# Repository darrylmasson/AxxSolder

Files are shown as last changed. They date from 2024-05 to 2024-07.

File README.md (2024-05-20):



Note - this is a fork of AxxSolder that replaces the MCU with the RP2040 because I felt like it. Major portions of this README will be rewritten at some point.

# AxxSolder Overview
AxxSolder is a STM32 based soldering iron controller for JBC C115, C210 and C245 cartridges. 
Two different versions are designed around the same PCB and software - one soldering station based on the [JBC ADS stand](https://www.jbctools.com/ad-sf-stand-for-t210-t245-handles-product-2018.html) and one portable version. The hardware takes a USB-C Power Delivery source. If a 65W, 20V USB-PD supply is used then NT115 and T210 handles can be powered at full power and T245 at limited power. The software is written for the RP2040 and implements a PID for temperature control, TFT display driver, sleep function when the handle is at rest and functions for read/write user settings to flash. Enclosures for both station and portable versions are 3D printed and design files are available under [/CAD](https://github.com/AxxAxx/AxxSolder/tree/main/CAD). A video showing the AxxSolder station can be found under [DEMO](#demo). A *bill of materials* (BOM) with individual component prices can be found under [/bom](https://github.com/AxxAxx/AxxSolder/tree/main/AxxSolder_hardware/bom).  
coverphoto

# Questions and support
Please use [Discord](https://discord.gg/dRD2ZfmyHY) for build related and general questions.

# Table of Contents
- [AxxSolder Overview](#axxsolder-overview)
- [Questions and support](#questions-and-support)
- [Features](#features)
- [Cartridge differences](#cartridge-differences)
- [Schematic](#schematic)
- [PCB](#pcb)
- [Software Version History and Hardware Compatibility](#software-version-history-and-hardware-compatibility)
- [DEMO](#demo)
- [AxxSolder Station](#axxsolder-station)
- [AxxSolder Portable](#axxsolder-portable)
- [Recommended power supply](#recommended-power-supply)
- [Handle identification and connections](#handle-identification-and-connections)
- [Firmware update](#firmware-update)
- [First start up after build](#first-start-up-after-build)
- [Settings](#settings)
- [PID control](#pid-control)
- [Temperature calibration](#temperature-calibration)
- [Temperature measurement](#temperature-measurement)

# Features
- The tip temperature is set by a rotary encoder. Pressing the encoder puts AxxSolder into Sleep mode and heating is turned off, press again to wake up.  
- AxxSolder is capable of driving C115, C210 and C245 style cartridges from JBC. With the "H_sense1" and "H_sense2" inputs AxxSolder can determine if the connected handle is either a NT115, T210 or T245 and adjust max output power accordingly. The max power output is limited in software to 120W for T245, 60W for T210 and 20W for NT115 handles.
- When the handle is put into the stand (connected to Stand_sense) AxxSolder goes into "Standby mode". On the portable version an aluminium plate is mounted and allows the AxxSolder to go into Standby mode when the cartridge or handle rests against it. After 10 min in Standby mode AxxSolder goes into "Sleep mode" and turns heating completely off. This is similar to what JBC calls [Sleep and Hibernation](https://www.jbctools.com/intelligent-heat-management.html).  
- If AxxSolder is left in normal running mode for longer than 30 min, the station automatically goes into sleep mode after 30 min as a safety feature.  
- Should the temperature ever go higher than 480 deg C overheating is detected and the station goes into sleep mode in order to protect the tip.
- User settings are stored in non volatile flash and can be configured via a settings menu described in [SETTINGS](#settings).
- The two buttons are used to store temperature presets, e.g. 330 deg C and 430 deg C. Both preset temperatures are configurable in the settings menu.
- The TFT display used in this project is a 2 inch 320x240 Color TFT display [2.0" 320x240 Color IPS TFT Display](https://www.adafruit.com/product/4311) and shows information about:
  - Set temperature
  - Actual temperature
  - Current power as a bar graph
  - In case of sleep mode, the power bar shows "ZzZzZz"
  - In case of Standby mode, the power bar shows "STANDBY"
  - Input voltage
  - MCU temperature
  - Current detected handle type

# Cartridge differences
Cartridges from JBC do all contain a thermocouple element to read the tip temperature and a resistive heater element. The configuration of thermocouple and heater element differ slightly between cartridge models. In order to determine the internal configuration of the cartridges two cross sections were done. These show clearly how the C210 and C245 cartridges are constructed internally. The images can be seen here: [https://www.eevblog.com/forum/projects/axxsolder-jbc-soldering-controller](https://www.eevblog.com/forum/projects/axxsolder-jbc-soldering-controller/msg5124267/#msg5124267).
As the thermocouple output also differs (see my measurements [Temperature calibration](#temperature-calibration)) the correct handle/cartridge type has to be set. This is done automatically be the inputs "Handle_sense_1" and "Handle_sense_2" This can be done thanks to the design of the handle connector. For the JCB T210 handle pin 5 and 6 are connected internally in the connector and for NT115 pin 3 and 5 should be connected. This allows AxxSolder to sense which handle is connected and assign correct thermocouple correction, PID parameters and max output power.

# Schematic
The schematic for AxxSolder is shown below. Both station and portable versions use the same PCB and software. The MCU is a [STM32G431CBT6](https://www.st.com/en/microcontrollers-microprocessors/stm32g431cb.html). 
AxxSolder_station

# PCB
The PCBs are designed in KiCad and manufactured by [PCBWay](https://www.pcbway.com/). PCBWay has sponsored this project with PCBs and stencils. As usual the quality of the PCBs is great. As some components have a rather fine pitch (0,5 mm as of the LQFP-48 package of the STM32) and some packages are "no lead" with a bottom thermal pad e.g. the WSON-8 package of the OPA2387 it is suggested to use a stencil to apply solder paste and then reflow the board using either a reflow oven or hot-plate. The boards on the image below were reflowed on a hot-plate (a homemade AxxPlate). A microscope is also recommended and helpful during assembly.
Printed Circuit Boards with assembled components are shown in the image below.
PCB_image
A 3D view (from and back) of the AxxSolder PCB is generated with KiCad and shown below. 
PCB_3D

# Software Version History and Hardware Compatibility
| Version | Date  | Hardware Compatibility |
|---|---|---|
|[v3.0.2](https://github.com/AxxAxx/AxxSolder/releases/tag/v3.0.1)|Apr 25, 2024|V3.*|
|[v3.0.1](https://github.com/AxxAxx/AxxSolder/releases/tag/v3.0.1)|Mar 26, 2024|V3.*|
|[v3.0.0](https://github.com/AxxAxx/AxxSolder/releases/tag/v3.0.0)|Mar 02, 2024|V3.*|
|[v2.2.4](https://github.com/AxxAxx/AxxSolder/releases/tag/v2.2.2)|Dec 11, 2023|V2.*|
|[v2.2.4](https://github.com/AxxAxx/AxxSolder/releases/tag/v2.2.2)|Nov 28, 2023|V2.*|
|[v2.2.3](https://github.com/AxxAxx/AxxSolder/releases/tag/v2.2.2)|Nov 25, 2023|V2.*|
|[v2.2.2](https://github.com/AxxAxx/AxxSolder/releases/tag/v2.2.2)|Oct 24, 2023|V2.*|
|[v2.2.0](https://github.com/AxxAxx/AxxSolder/releases/tag/v2.2.0)|Oct 20, 2023|V2.*|
|[v2.1.3-revC](https://github.com/AxxAxx/AxxSolder/releases/tag/v2.1.3-revC)|Oct 16, 2023|V2.*|
|[v2.1.1](https://github.com/AxxAxx/AxxSolder/releases/tag/v2.1.1)|Oct 7, 2023|V2.*|
|[v2.1.0](https://github.com/AxxAxx/AxxSolder/releases/tag/v2.1.0)|Oct 7, 2023|V2.*|

# DEMO
(This shows AxxSolder 2 and not the latest AxxSolder 3)  
Click on the gif to get to YouTube and see the demo in full resolution.  
AxxSolder DEMO (https://www.youtube.com/watch?v=-3MtJyTwZFQ)

# AxxSolder Station
The preferred setup is to pair AxxSolder with the [JBC ADS stand](https://www.jbctools.com/ad-sf-stand-for-t210-t245-handles-product-2018.html). This makes a very nice, compact and powerful soldering station. The JBC ADS stand is paired with a custom 3D printed enclosure for AxxSolder and the PCB is mounted with two mounting brackets. All 3D printed parts are available under [/CAD](https://github.com/AxxAxx/AxxSolder/tree/main/CAD). 
AxxSolder_station  
The JBC ADS stand comes with a silicone cable fitted with two Binder 99-0621-00-07 connectors. In order to use this cable a Binder 99-0624-00-07 is mounted into the AxxSolder enclosure and wired as the image below:  
AxxSolder_station  
By default, the stand separates the two signals coming from the "tool rest position" and the "tip change position" and does NOT have two separate connections for tip sensing 1 and 2 (as is needed). Therefore, a modification is done to the PCB inside the JBC ADS stand in order to combine the "tool rest position" and the "tip change position" sense into one connection and separate the two tip sense connections. This is shown in the image above. The stand is held together with two PH0 screws from the side. 

# AxxSolder Portable
It is often nice to have a compact and portable soldering iron controller for when you are away from your comfortable desk. A neat powerful package with the same capabilities as your main soldering station. This is why AxxSolder Portable was designed. The only difference between AxxSolder station and Portable is the enclosure. As AxxSolder accepts an input of 9-24 V it is compatible with a range of battery options. The author usually use a battery pack consisting of 12 Samsung INR18650 35E in a 3S4P configuration which works very well. The portable version has an aluminium tab on the enclosure connected to the same input on the PCB as the "handle rest" on the station version. This allows the user to rest the iron onto the aluminium tab and automatically enter sleep mode.   
AxxSolder_portable
The connections from the handle to the PCB through the Hirose RPC1-12RB-6P(71) connector is shown below. The blue wire in the portable version is connected to the aluminium plate which tells the AxxSolder to go into sleep mode when in contact with the soldering iron. The yellow wire is connected to pin 6 and is used to determine which handle is connected.
AxxSolder_portable
# Recommended power supply
A well-suited power supply with isolated output (SELV) is the Meanwell LRS-150-24. It is rated for 156 W at 24 V. A cover protecting the terminals for this power supply can be found under [/CAD](https://github.com/AxxAxx/AxxSolder/tree/main/CAD).  
LRS-150-24

# Handle identification and connections
In order for AxxSolder to know which type of handle (NT115, T210, T245) is connected specific pins must be connected within the handle connector. By default, the original JBC handle T245 has NO pins connected while in the original T210 pins 5 and 6 are connected. The original NT115 handle has a different connector from JBC and must be modified. If the user changes the connector or uses a non-genuine handle it is important to make sure that pin 5 and 3 is connected within the connector. All the necessary connections are shown in the image below. While powering on AxxSolder fir the first time after doing these connections within the handle connector or connections to AxxSolder it is wise to attach a handle without its cartridge and ensure that AxxSolder shows the correct handle type on the display. Failing to detect the handle type will cause damage to the tip as the thermal calibration and max power allowed will be wrong.  
Handle_connections

# Firmware update
Programming or updating the firmware the STM32 MCU can be done in two ways, by using a SWD programmer or directly via USB. 
## SWD programmer
These come in a variety of models and are available from several different places online. In the below example a [STLINK-V3MINIE](https://www.st.com/en/development-tools/stlink-v3minie.html) SWD programmer is used. The MCU is programmed by the following steps:
1. Disconnect any soldering iron handles from AxxSolder during the firmware update process.
2. Download the latest AxxSolder.bin file from [Releases](https://github.com/AxxAxx/AxxSolder/releases)
3. Connect your SWD programmer to the target MCU with GND, 3.3V, (N)RST, SWCLK, SWDIO
4. If your SWD programmer *can not* supply 3.3V it is necessary to power the AxxSolder from an external supply.
5. Start your programming software. [STM32CubeProgrammer](https://www.st.com/en/development-tools/stm32cubeprog.html) is used in this example.
6. Connect to the target by selecting *ST-LINK* and click on *Connect*
7. Load the latest AxxSolder.bin downloaded in *Step 2* by clicking *Open file* and select the downloaded binary file.
8. Write the firmware to the MCU by clicking *Download*.
9. If you get the message *File download complete* everything succeeded and the SWD programmer can be disconnected and AxxSolder power cycled once and AxxSolder should boot.


AxxSolder_SWD_programming
## USB (DFU mode)
1. Disconnect any soldering iron handles from AxxSolder during the firmware update process.
2. Download the latest AxxSolder.bin file from [Releases](https://github.com/AxxAxx/AxxSolder/releases)
3. Connect AxxSolder via USB to a computer that runs [STM32CubeProgrammer](https://www.st.com/en/development-tools/stm32cubeprog.html).
4. Hold down the most right button while powering on AxxSolder to enter DFU mode.
5. Connect to the target by selecting *USB* and click on *Connect*
6. Load the latest AxxSolder.bin downloaded in *Step 2* by clicking *Open file* and select the downloaded binary file.
7. Write the firmware to the MCU by clicking *Download*.
8. If you get the message *File download complete* everything succeeded and the USB cable can be disconnected.
9. Power cycle once and AxxSolder should boot.

# First start up after build
The first start up after you have built your AxxSolder can be intense. Double check all solder connections under a loupe/microscope. Especially the OPA2387, LTC4440 and the STM32G431 are small packages with tight pad spacing and can have solder bridges. Do also double check the connections to the soldering iron/stand which are shown in this document under [AxxSolder Station](#axxsolder-station) and [AxxSolder Portable](#axxsolder-portable).  
The first thing to do after you have double-checked everything is to follow the steps under [Firmware update](#firmware-update). It is wise to do the first programming of AxxSolder without any handle piece and with only 3.3 V, not VDD. After the programming is done you can now power up AxxSolder again via either with 3.3 V, this time you can attach your handle. This allows you to test that your handle type is detected correctly (the detected handle type NT115/T210/T245 is shown in the display). The Standby feature can also be tested by touching the stand (STAND Input).  
If the handle is detected correctly, the Standby function works and the display works you proceed to test the 7.35V DC/DC. This is done by once again disconnect the handle, but this time apply current limited 9-24 V VDD. 100 mA at 24 V is enough to check that the display starts and that you can measure the 3 bus voltages; 3.3V, 7.35V and VDD. If the bus voltages look good and the display shows the main screen you are ready to apply full VDD power and attach the soldering handle.  
If you are not 110% sure about your soldering/connections it is wise to be on the safe side and keep your soldering tip in a water bath in over to prevent it from over-heating in an uncontrolled manner. During the development this method was used and saved a few of those expensive JBC cartridges..

# Settings
To access the user settings the user holds down the encoder button at start-up. A SETTINGS text is then presented and the button can be released. While in the settings there are several parameters available.
| Setting | Desciption  | Unit | Default |
|---|---|---|---|
|Startup Temp|Default temperature selected after boot|deg C|330|
|Temp Offset|Temperature offset applied to measured temperature|deg C|0|
|Standby Temp|Temperature to go to after handle is set in stand|deg C|150|
|Standby Time|Time for which standby temperature is held before cooling down|minutes|10|
|Sleep Time|Time that the iron can be ON before cooling down (safety feature)|minutes|30|
|Buzzer Enable|Enable or Disable the buzzer|ON/OFF|ON|
|Preset Temp 1|Preset temperature for button 1|deg C|330|
|Preset Temp 2|Preset temperature for button 2|deg C|430|
|GPIO4 ON at run|Enable 3.3V output on GPIO4 when the iron is in run mode|ON/OFF|OFF|
|Screen rotation|Rotate the screen|"0"=-180 deg, "1"=-90 deg, "2"=0 deg, "3"=90 deg|2|
|Limit Power|Limit the output power|"0"=no user limit, "1"=10 W, "2"= 20 W, "3"= 30 W ...|0|
|-Load Default-|Load default parameters|N/A|N/A|
|-Save and Reboot-|Exit and Save|N/A|N/A|
|-Exit no Save-|Exit without Save|N/A|N/A|

# PID control
As the thermal mass of each cartridge differs the PID parameters should in theory be adjusted to each different cartridge. As a matter of simplification, the PID parameters are only different between the different handle types, NT115, T210 and T245. This gives a good enough PID performance in my tests. The Max allowed power is also different between handle types.
```c
	/* Determine if NT115 handle is detected */
	if((sensor_values.handle1_sense >= 0.5) && (sensor_values.handle2_sense < 0.5)){
		handle = NT115;
		sensor_values.max_power_watt = 20; //20W
		Kp = 3;
		Ki = 1;
		Kd = 0.25;
		PID_MAX_I_LIMIT = 100;
	}
	/* Determine if T210 handle is detected */
	else if((sensor_values.handle1_sense < 0.5) && (sensor_values.handle2_sense >= 0.5)){
		handle = T210;
		sensor_values.max_power_watt = 60; //60W
		Kp = 5;
		Ki = 5;
		Kd = 0.5;
		PID_MAX_I_LIMIT = 125;
	}
	else{
		handle = T245;
		sensor_values.max_power_watt = 120; //120W
		Kp = 8;
		Ki = 3;
		Kd = 0.5;
		PID_MAX_I_LIMIT = 150;
	}
	PID_SetTunings(&TPID, Kp, Ki, Kd); // Update PID parameters based on handle type
	PID_SetILimits(&TPID, -PID_MAX_I_LIMIT, PID_MAX_I_LIMIT); 	// Set max and min I limit
```
The PID parameters are adjusted to achieve a fast response with minimum overshoot and oscillation. The below image is showing the set temperature, actual temperature response as well as the P, I and D contributions during a heat-up cycle from 25 deg C to 330 deg C. This heat-up sequence takes ~1.5 seconds for a C210-007 cartridge.  

 AxxSolder_pid
# Temperature calibration
The voltage from the thermocouple embedded inside the cartridge is amplified by an OPA2387 operational amplifier and then read by the ADC of the MCU. To correlate the measured ADC value to the cartridge temperature experiments were done. A constant power was applied to the heating element of the cartridge and the ADC value was read as well as the actual tip temperature. The tip temperature was measured by a "Soldering Tip Thermocouple" used in e.g. the Hakko FG-100.   
The measured data was recorded and plotted for both the C115, C210 and C245 cartridges. The specific cartridges used were the C115112, C210-007 and C245-945. The measured data were fitted to polynomial equations:  
$Temp_{C115}[deg] =  5.10e^{-5} * ADC^2 + 0.42* ADC + 20.15$  
$Temp_{C210}[deg] =  4.22e^{-6} * ADC^2 + 0.32* ADC + 20.97$  
$Temp_{C245}[deg] = -4.73e^{-7} * ADC^2 + 0.12* ADC + 23.78$  
These are then used in the software to retrieve correct tip temperatures.
Temp_calibration
# Temperature measurement
As the thermocouple and heater element is connected in series inside the JBC cartridges and the thermocouple voltage measures over the same pins as the heating element we have to be careful when to do the temperature measurement. In order to not disturb the thermocouple measurement with heater element switching, the switching is turned off for 0.5 ms just before the temperature measurement is taken. The 0.5 ms delay ensures that the switching is turned off and the thermocouple signal is stabilized around a stable voltage.  
The measured signal over the thermocouple is clamped to 3.3V with a BAV199 Schottky diode in order to protect the op-amp OPA2387. The voltage measurement is taken by the internal ADC in DMA mode with a circular buffer. The buffer holds several measurements which are averaged and filtered in software.  
The yellow curve in the image below (Channel 1) shows the PWM signal driving the gate of the MOSFET. The green curve shows the amplified voltage between GREEN and RED wire in the JBC handle for at 330 degree C and 5% power and the purple 25 degree C and at 80% power (the tip held under water trying to heat up).
The blue pulse indicates the wait time of 0.5 ms and the purple pulse is where the ADC is sampled.
Oscilloscope_image_PWM
# Current measurement
The current is sampled four times per second by a 30 us current pulse through the heater. This is done both to check if there is a functioning tip in the handle (otherwise the display shows "---" at current temp) and to be able to calculate the power drawn by the heater. By knowing how much the heater draws in ampere the actual power can be calculated by knowing the bus voltage and pulse duty cycle. to measure the current the gate to the MOSFET is turned on, 10 us later the voltage over the current shunt is sampled by the ADC and the result is converted. This is shown the image below.
Oscilloscope_image_PWM
## Stargazers over time
Stargazers over time (https://starchart.cc/AxxAxx/AxxSolder)

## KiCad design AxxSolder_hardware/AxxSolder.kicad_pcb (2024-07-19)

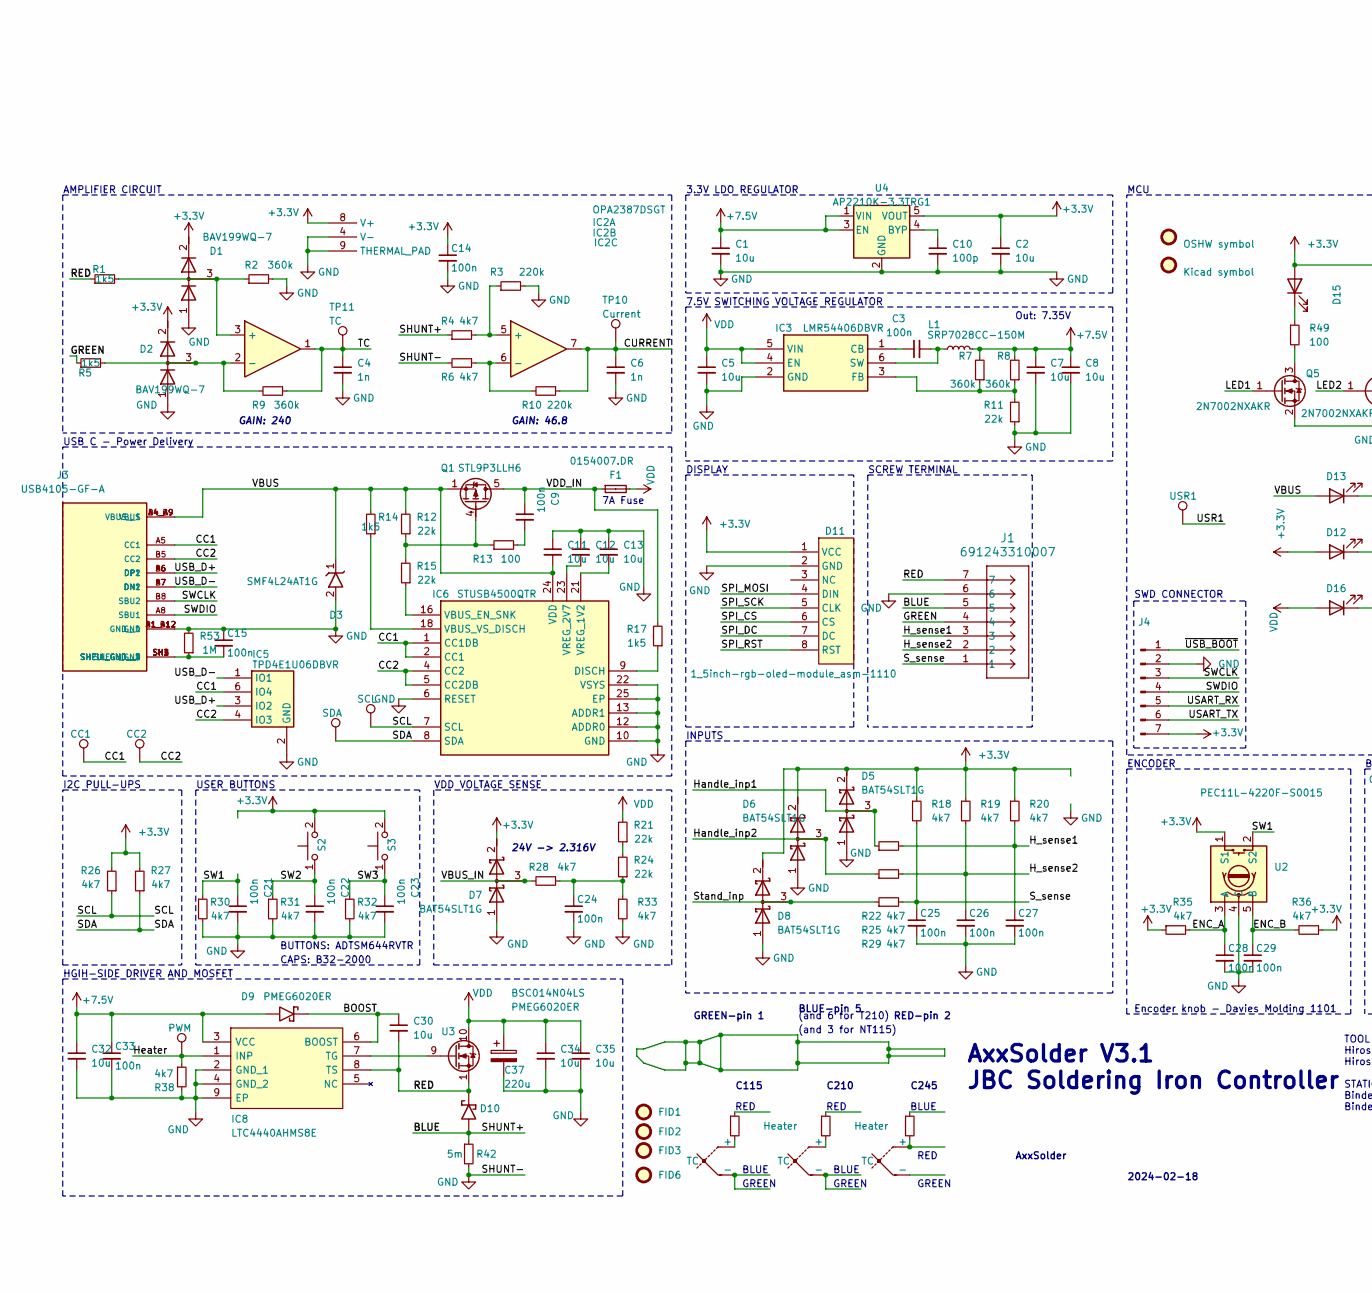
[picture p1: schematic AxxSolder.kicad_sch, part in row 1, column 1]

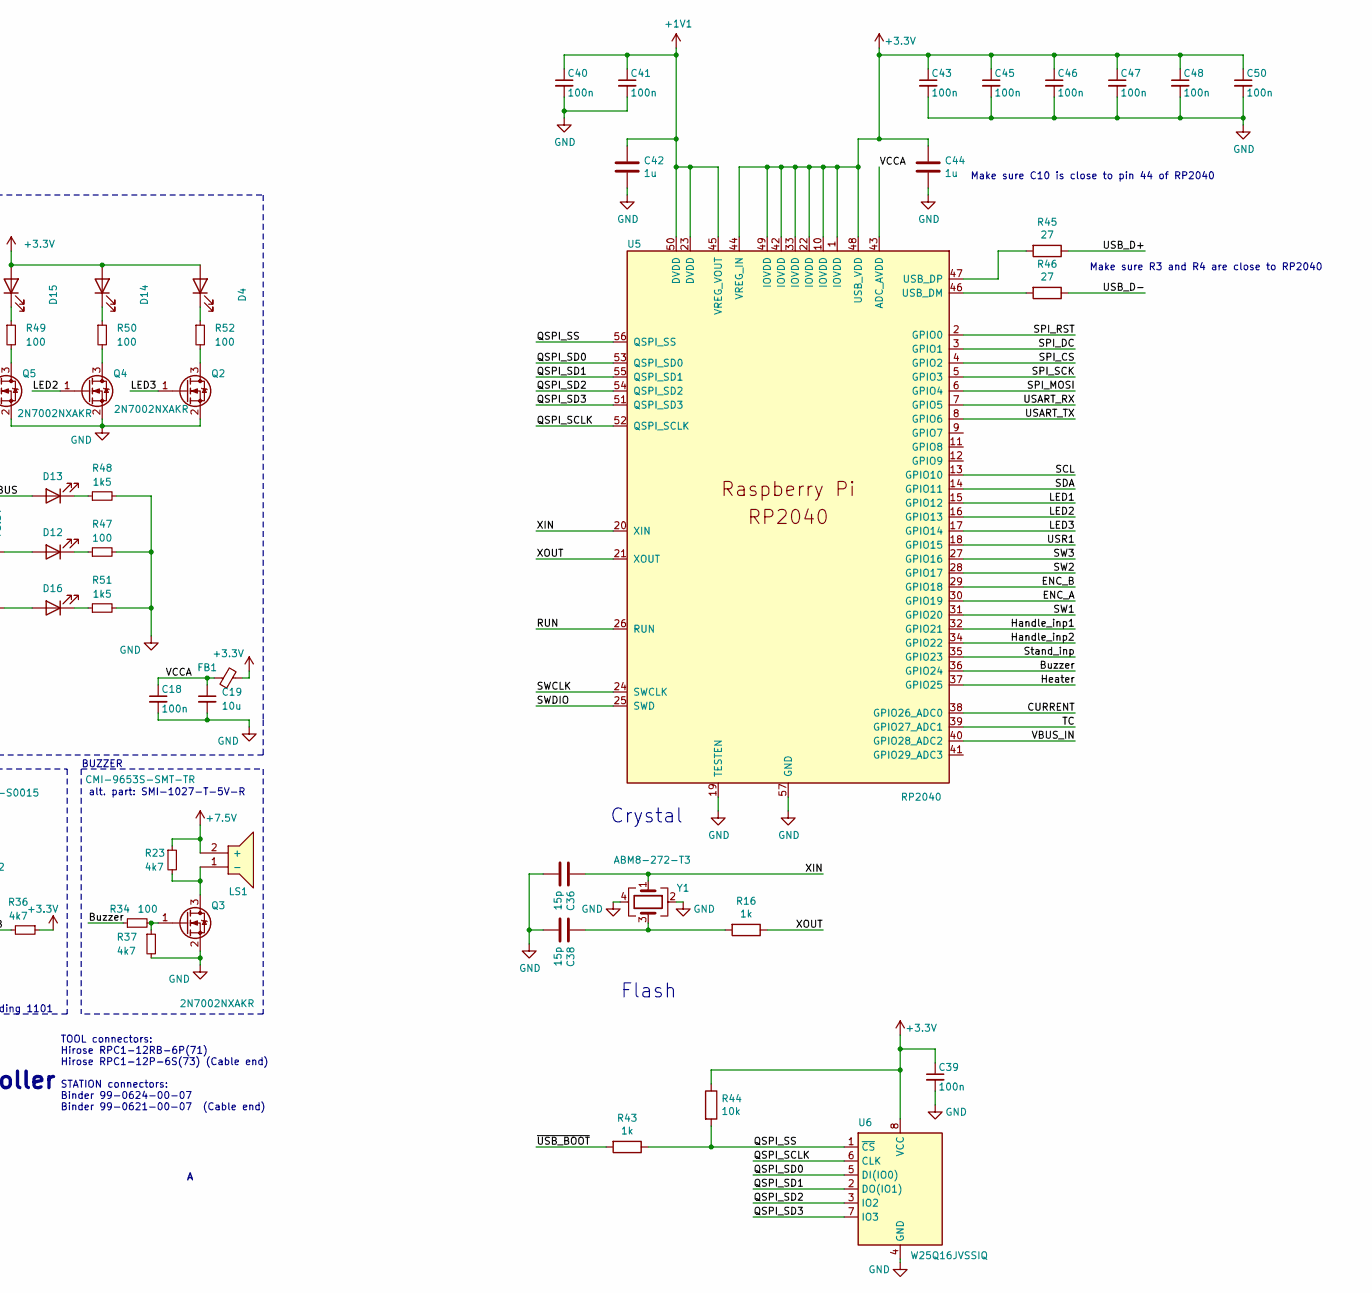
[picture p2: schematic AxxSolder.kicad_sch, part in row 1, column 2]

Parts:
C1, C2, C5, C7, C8, C11, C12, C13, C19, C30, C32, C34, C35: 10u; C_0603_1608Metric; DigiKey PN 1276-1869-1-ND
C3, C9, C14, C15, C18, C21, C22, C23, C24, C25, C26, C27, C28, C29, C33, C39, C40, C41, C43, C45, C46, C47, C48, C50: 100n; C_0603_1608Metric; DigiKey PN 311-1341-1-ND
C4, C6: 1n; C_0603_1608Metric; DigiKey PN 399-C0603C102K3RAC7867CT-ND
C10: 100p; C_0603_1608Metric; DigiKey PN 1276-1908-1-ND
C36, C38: 15p; C_0603_1608Metric; DigiKey PN 311-1060-1-ND
C37: 220u; CAPAE830X1050N; DigiKey PN 399-6708-1-ND
C42, C44: 1u; C_0603_1608Metric; DigiKey PN 311-1445-1-ND
D1: BAV199WQ-7; SOT65P210X110-3N; Mouser Part Number 621-BAV199WQ-7
D2: BAV199WQ-7; SOT65P210X110-3N; DigiKey PN BAV199WQ-7DICT-ND
D3: SMF4L24AT1G; SODFL3619X98N; DigiKey PN 18-SMF4L24AT1GCT-ND
D4, D12, D13, D14, D15, D16: 150060VS75000; LED_0603_1608Metric; DigiKey PN 732-4980-1-ND
D5: BAT54SLT1G; SOT95P230X110-3N; DigiKey PN BAT54SLT1GOSCT-ND
D6, D7, D8: BAT54SLT1G; SOT95P230X110-3N; Manufacturer_Part_Number BAT54S; Mouser Part Number 637-BAT54S
D9: PMEG6020ER; PMEG6020ER115; DigiKey PN 1727-5217-1-ND
D10: PMEG6020ER; PMEG6020ER115; Mouser Part Number 771-PMEG6020ER-115
D11: 1_5inch-rgb-oled-module_asm-1110
F1: 0154007.DR; 0154100DR; DigiKey PN F1229CT-ND
FB1: BLM18HE601SN1D; R_0603_1608Metric; DigiKey PN 490-5214-1-ND
FID1, FID2, FID3, FID6: Fiducial; Fiducial_0.75mm_Mask1.5mm
FID4: OSHW symbol; OSHW-Logo_5.7x6mm_Copper
FID5: Kicad symbol; KiCad-Logo_6mm_SilkScreen
IC2: OPA2387DSGT; SON50P200X200X80-9N; DigiKey PN 296-OPA2387DSGTCT-ND
IC3: LMR54406DBVR; SOT95P280X145-6N; DigiKey PN 296-LMR54406DBVRCT-ND
IC5: TPD4E1U06DBVR; SOT95P280X145-6N; DigiKey PN TPD4E1U06DBVR
IC6: STUSB4500QTR; QFN50P400X400X100-25N-D; DigiKey PN 497-18060-1-ND
IC8: LTC4440AHMS8E; SOP65P490X110-9N; DigiKey PN 505-LTC4440AHMS8E-5#PBF-ND
J1: 691243310007; DigiKey PN 732-691243310007-ND
J3: USB4105-GF-A; GCT_USB4105-GF-A; DigiKey PN 2073-USB4105-GF-ACT-ND
J4: Conn_01x07_Pin; PinHeader_1x07_P2.54mm_Vertical
L1: SRP7028CC-150M; INDPM7366X300N; DigiKey PN 118-SRP7028CC-150MCT-ND
LS1: CMI-9653S-SMT-TR; CMI9653SSMTTR; DigiKey PN 102-3737-1-ND
Q1: STL9P3LLH6; STL20N6F7; DigiKey PN 497-17897-1-ND
Q2, Q3, Q4: 2N7002NXAKR; SOT95P230X110-3N; Manufacturer_Part_Number 2N7002NXAKR; Mouser Part Number 771-2N7002NXAKR
Q5: 2N7002NXAKR; SOT95P230X110-3N; DigiKey PN 2N7002NXAKR
R1, R5, R14, R17: 1k5; R_0603_1608Metric; Manufacturer_Part_Number ERJ-H3ED1501V; Mouser Part Number 667-ERJ-H3ED1501V
R2, R7, R8, R9: 360k; R_0603_1608Metric; Manufacturer_Part_Number ERJ-3RED3603V; Mouser Part Number 667-ERJ-3RED3603V
R3, R10: 220k; R_0603_1608Metric; Manufacturer_Part_Number ERJ-3RED2203V; Mouser Part Number 667-ERJ-3RED2203V
R4, R6, R18, R19, R20, R22, R23, R25, R26, R27, R28, R29, R30, R31, R32, R33, R35, R36, R37, R38: 4k7; R_0603_1608Metric; Manufacturer_Part_Number ERJ-3RBD4701V; Mouser Part Number 667-ERJ-3RBD4701V
R11, R12, R15, R21, R24: 22k; R_0603_1608Metric; Manufacturer_Part_Number ERJ-UP3J223V; Mouser Part Number 667-ERJ-UP3J223V
R13, R34: 100; R_0603_1608Metric; Manufacturer_Part_Number ERJ-P03F1000V; Mouser Part Number 667-ERJ-P03F1000V
R16, R43: 1k; R_0603_1608Metric; DigiKey PN 311-1.00KHRCT-ND
R39, R40: Heater
R41: Heater 2 OHM
R42: 5m; RESC6432X89N; DigiKey PN 541-10153-1-ND
R44: 10k; R_0603_1608Metric; DigiKey PN 311-10.0KHRCT-ND
R45, R46: 27; R_0603_1608Metric; DigiKey PN CR0603-FX-27R0ELFCT-ND
R47, R49, R50, R52: 100; R_0603_1608Metric; Manufacturer_Part_Number ERJ-3RBD4701V; Mouser Part Number 667-ERJ-3RBD4701V
R48, R51: 1k5; R_0603_1608Metric_Pad0.98x0.95mm_HandSolder; Manufacturer_Part_Number ERJ-3RBD4701V; Mouser Part Number 667-ERJ-3RBD4701V
R53: 1M; R_0603_1608Metric; Manufacturer_Part_Number ERJ-UP3J223V; Mouser Part Number 667-ERJ-UP3J223V
S2, S3: ADTSM644RVTR; DigiKey PN 679-ADTSM644RVTRCT-ND
TC1, TC2, TC3: TC
TP1: USR1; TestPoint_Pad_D1.0mm
TP7: CC1; TestPoint_Pad_D1.0mm
TP8: CC2; TestPoint_Pad_D1.0mm
TP10: Current; TestPoint_Pad_D1.0mm
TP11: TC; TestPoint_Pad_D1.0mm
TP15: SCL; TestPoint_Pad_D1.0mm
TP16: SDA; TestPoint_Pad_D1.0mm
TP17: PWM; TestPoint_Pad_D1.0mm
U2: PEC11L-4220F-S0015; PEC11L4220FS0015; DigiKey PN PEC11L-4220F-S0015-ND
U3: BSC014N04LS; DigiKey PN BSC014N04LSATMA1CT-ND
U4: AP2210K-3.3TRG1; SOT-23-5; DigiKey PN AP2210K-3.3TRG1DICT-ND
U5: RP2040; RP2040-QFN-56; DigiKey PN 2648-SC0914(13)CT-ND
U6: W25Q16JVSSIQ; SOIC-8_5.23x5.23mm_P1.27mm; DigiKey PN W25Q16JVSSIQ-ND
Y1: ABM8-272-T3; Crystal_SMD_3225-4Pin_3.2x2.5mm; DigiKey PN 535-ABM8-272-T3CT-ND

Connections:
+1V1: C40.1, C41.1, C42.1, U5.23 (DVDD), U5.45 (VREG_VOUT), U5.50 (DVDD)
+3.3V: C2.1, C14.1, C39.1, C43.1, C44.1, C45.1, C46.1, C47.1, C48.1, C50.1, D1.2, D2.2, D4.2 (A), D5.2 (K), D6.2 (K), D7.2 (K), D8.2 (K), D11.1 (VCC), D12.2 (A), D14.2 (A), D15.2 (A), FB1.2, IC2.8 (V+), J4.7, R18.1, R19.1, R20.1, R26.2, R27.2, R35.1, R36.1, R44.1, S2.2, S3.2, U2.1 (S1), U4.5 (VOUT), U5.1 (IOVDD), U5.10 (IOVDD), U5.22 (IOVDD), U5.33 (IOVDD), U5.42 (IOVDD), U5.44 (VREG_IN), U5.48 (USB_VDD), U5.49 (IOVDD), U6.8 (VCC)
+7.5V: C1.1, C7.1, C8.1, C32.1, C33.1, D9.2, IC8.3 (VCC), L1.2, LS1.2 (+), R7.2, R8.2, R23.1, U4.1 (VIN), U4.3 (EN)
/BLUE: D10.2, J1.5, R4.1, R42.1
/BOOST: C30.1, D9.1, IC8.6 (BOOST)
/Buzzer: R34.1, U5.36 (GPIO24)
/CC1: IC5.6 (IO4), IC6.1 (CC1DB), IC6.2 (CC1), J3.A5 (CC1), TP7.1
/CC2: IC5.4 (IO3), IC6.4 (CC2), IC6.5 (CC2DB), J3.B5 (CC2), TP8.1
/CURRENT: C6.1, IC2.7, R10.1, TP10.1, U5.38 (GPIO26_ADC0)
/ENC_A: C28.1, R35.2, U2.3 (A), U5.30 (GPIO19)
/ENC_B: C29.1, R36.2, U2.5 (B), U5.29 (GPIO18)
/GREEN: J1.4, R5.1
/H_sense1: C27.1, J1.3, R20.2, R22.2
/H_sense2: C26.1, J1.2, R19.2, R25.2
/Handle_inp1: D5.3 (common), R22.1, U5.32 (GPIO21)
/Handle_inp2: D6.3 (common), R25.1, U5.34 (GPIO22)
/Heater: IC8.1 (INP), R38.1, TP17.1, U5.37 (GPIO25)
/LED1: Q5.1 (G), U5.15 (GPIO12)
/LED2: Q4.1 (G), U5.16 (GPIO13)
/LED3: Q2.1 (G), U5.17 (GPIO14)
/QSPI_SCLK: U5.52 (QSPI_SCLK), U6.6 (CLK)
/QSPI_SD0: U5.53 (QSPI_SD0), U6.5 (DI(IO0))
/QSPI_SD1: U5.55 (QSPI_SD1), U6.2 (DO(IO1))
/QSPI_SD2: U5.54 (QSPI_SD2), U6.3 (IO2)
/QSPI_SD3: U5.51 (QSPI_SD3), U6.7 (IO3)
/QSPI_SS: R43.1, R44.2, U5.56 (QSPI_SS), U6.1 (~CS)
/RED: C30.2, D10.1, IC8.8 (TS), J1.7, R1.1, U3.1 (S)
/RUN: U5.26 (RUN)
/SCL: IC6.7 (SCL), R26.1, TP15.1, U5.13 (GPIO10)
/SDA: IC6.8 (SDA), R27.1, TP16.1, U5.14 (GPIO11)
/SPI_CS: D11.6 (CS), U5.4 (GPIO2)
/SPI_DC: D11.7 (DC), U5.3 (GPIO1)
/SPI_MOSI: D11.4 (DIN), U5.6 (GPIO4)
/SPI_RST: D11.8 (RST), U5.2 (GPIO0)
/SPI_SCK: D11.5 (CLK), U5.5 (GPIO3)
/SW1: C21.1, R30.1, U2.2 (S2), U5.31 (GPIO20)
/SW2: C22.1, R31.1, S2.1, U5.28 (GPIO17)
/SW3: C23.1, R32.1, S3.1, U5.27 (GPIO16)
/SWCLK: J3.B8 (SBU2), J4.3, U5.24 (SWCLK)
/SWDIO: J3.A8 (SBU1), J4.4, U5.25 (SWD)
/S_sense: C25.1, J1.1, R18.2, R29.2
/Stand_inp: D8.3 (common), R29.1, U5.35 (GPIO23)
/TC: C4.1, IC2.1, R9.1, TP11.1, U5.39 (GPIO27_ADC1)
/USART_RX: J4.5, U5.7 (GPIO5)
/USART_TX: J4.6, U5.8 (GPIO6)
/USB_D+: IC5.3 (IO2), J3.A6 (DP1), J3.B6 (DP2), R45.1
/USB_D-: IC5.1 (IO1), J3.A7 (DN1), J3.B7 (DN2), R46.1
/USR1: TP1.1, U5.18 (GPIO15)
/VBUS: C11.2, D3.1 (K), D13.2 (A), IC6.24 (VDD), J3.A4_B9 (VBUS), J3.B4_A9 (VBUS__1), Q1.1 (S), R12.2, R14.2
/VBUS_IN: D7.3 (common), R28.2, U5.40 (GPIO28_ADC2)
/VCCA: C18.1, C19.1, FB1.1, U5.43 (ADC_AVDD)
/VDD_IN: C9.1, F1.1, Q1.5 (D), R17.2
/XIN: C36.1, U5.20 (XIN), Y1.1
/XOUT: R16.1, U5.21 (XOUT)
/~USB_BOOT: J4.1, R43.2
GND: C1.2, C2.2, C4.2, C5.2, C6.2, C7.2, C8.2, C10.2, C11.1, C12.1, C13.1, C14.2, C15.1, C18.2, C19.2, C21.2, C22.2, C23.2, C24.2, C25.2, C26.2, C27.2, C28.2, C29.2, C32.2, C33.2, C34.2, C35.2, C36.2, C37.2, C38.2, C39.2, C40.2, C41.2, C42.2, C43.2, C44.2, C45.2, C46.2, C47.2, C48.2, C50.2, D1.1, D2.1, D3.2 (A), D5.1 (A), D6.1 (A), D7.1 (A), D8.1 (A), D11.2 (GND), IC2.4 (V-), IC2.9 (THERMAL_PAD), IC3.2 (GND), IC5.2 (GND), IC6.6 (RESET), IC6.10 (GND), IC6.12 (ADDR0), IC6.13 (ADDR1), IC6.22 (VSYS), IC6.25 (EP), IC8.2 (GND_1), IC8.4 (GND_2), IC8.9 (EP), J1.6, J3.A1_B12 (GND), J3.B1_A12 (GND__1), J4.2, Q2.2 (S), Q3.2 (S), Q4.2 (S), Q5.2 (S), R2.2, R3.2, R6.2, R11.1, R30.2, R31.2, R32.2, R33.2, R37.2, R38.2, R42.2, R47.2, R48.2, R51.2, R53.2, U2.4 (C), U4.2 (GND), U5.19 (TESTEN), U5.57 (GND), U6.4 (GND), Y1.2, Y1.4
unnamed: C9.2, R13.2
unnamed: C24.1, R24.1, R28.1, R33.1
unnamed: C38.1, R16.2, Y1.3
unnamed: D4.1 (K), R52.1
unnamed: D12.1 (K), R47.1
unnamed: D13.1 (K), R48.1
unnamed: D14.1 (K), R50.1
unnamed: D15.1 (K), R49.1
unnamed: D16.1 (K), R51.1
unnamed: D1.3, IC2.3 (+), R1.2, R2.1
unnamed: D2.3, IC2.2 (-), R5.2, R9.2
unnamed: IC2.5 (+), R3.1, R4.2
unnamed: IC2.6 (-), R6.1, R10.2
unnamed: C3.1, IC3.1 (CB)
unnamed: IC3.3 (FB), R7.1, R8.1, R11.2
unnamed: C3.2, IC3.6 (SW), L1.1
unnamed: IC6.9 (DISCH), R17.1
unnamed: IC6.16 (VBUS_EN_SNK), R15.1
unnamed: IC6.18 (VBUS_VS_DISCH), R14.1
unnamed: C13.2, IC6.21 (VREG_1V2)
unnamed: C12.2, IC6.23 (VREG_2V7)
unnamed: IC8.7 (TG), U3.9 (G)
unnamed: C15.2, J3.SH1 (SHELL_GND), J3.SH2 (SHELL_GND__1), J3.SH3 (SHELL_GND__2), J3.SH4 (SHELL_GND__3), R53.1
unnamed: LS1.1 (-), Q3.3 (D), R23.2
unnamed: Q1.4 (G), R12.1, R13.1, R15.2
unnamed: Q2.3 (D), R52.2
unnamed: Q3.1 (G), R34.2, R37.1
unnamed: Q4.3 (D), R50.2
unnamed: Q5.3 (D), R49.2
unnamed: R21.1, R24.2
unnamed: R39.2, TC1.1 (+)
unnamed: R40.2, TC2.1 (+)
unnamed: R41.2, TC3.1 (+)
unnamed: C10.1, U4.4 (BYP)
unnamed: R46.2, U5.46 (USB_DM)
unnamed: R45.2, U5.47 (USB_DP)
VDD: C5.1, C34.1, C35.1, C37.1, D16.2 (A), F1.2, IC3.4 (EN), IC3.5 (VIN), R21.2, U3.10 (D)

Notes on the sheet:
USER BUTTONS
C115
7A Fuse
Encoder knob - Davies Molding 1101
USB C - Power Delivery
BUTTONS: ADTSM644RVTR
Make sure R3 and R4 are close to RP2040
MCU
CAPS: B32-2000
Flash
GREEN
(and 3 for NT115)
GREEN-pin 1
RED
alt. part: SMI-1027-T-5V-R
(and 6 for T210)
SCREW TERMINAL
AMPLIFIER CIRCUIT
24V -> 2.316V
Crystal
VDD VOLTAGE SENSE
C245
ENCODER
SWD CONNECTOR
BLUE
BLUE-pin 5
2024-02-18
Make sure C10 is close to pin 44 of RP2040
BUZZER
7.5V SWITCHING VOLTAGE REGULATOR
AxxSolder V3.1 JBC Soldering Iron Controller
TOOL connectors: Hirose RPC1-12RB-6P(71) Hirose RPC1-12P-6S(73) (Cable end) STATION connectors: Binder 99-0624-00-07 Binder 99-0621-00-07 (Cable end)
C210
INPUTS
HGIH-SIDE DRIVER AND MOSFET
AxxSolder
RED-pin 2
RED
Out: 7.35V
I2C PULL-UPS

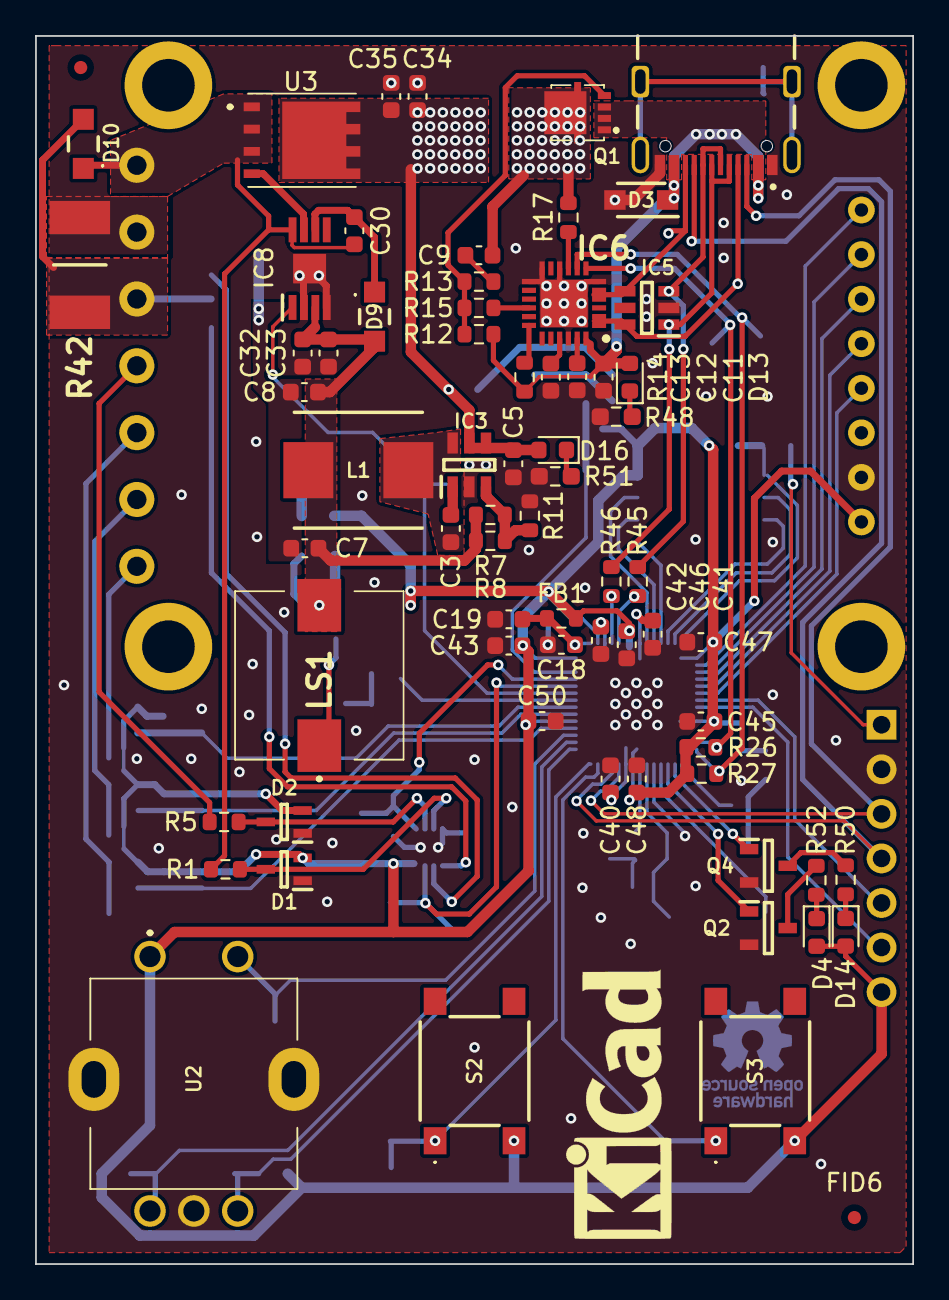
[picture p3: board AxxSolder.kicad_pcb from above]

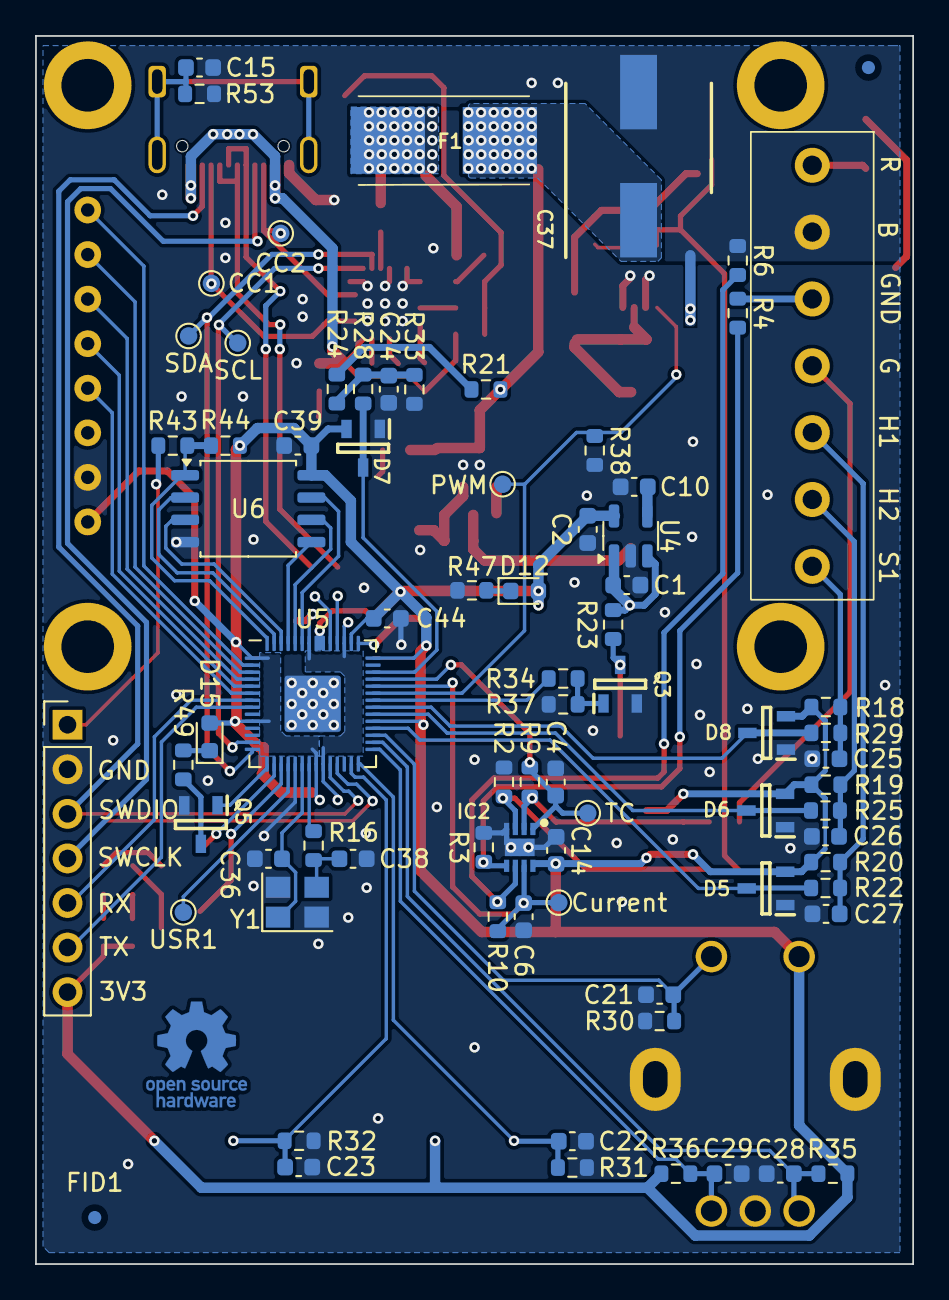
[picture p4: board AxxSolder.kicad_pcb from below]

Board: 2 copper layers, 50.0 x 70.0 mm, 150 parts (79 on the bottom side), 89 nets.

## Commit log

2024-05-20 Replace MCU with RP2040, new PCB layout
    [AxxSolder.kicad_pcb, AxxSolder.kicad_sch]
2024-07-06 Best work yet
    [AxxSolder.kicad_pcb, AxxSolder.kicad_sch]
2024-07-19 Ordered this one
    [AxxSolder.kicad_pcb, AxxSolder.kicad_sch]

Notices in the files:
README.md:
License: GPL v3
